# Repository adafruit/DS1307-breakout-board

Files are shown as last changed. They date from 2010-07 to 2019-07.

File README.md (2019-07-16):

## Adafruit DS1307 Real Time Clock Assembled Breakout Board PCB

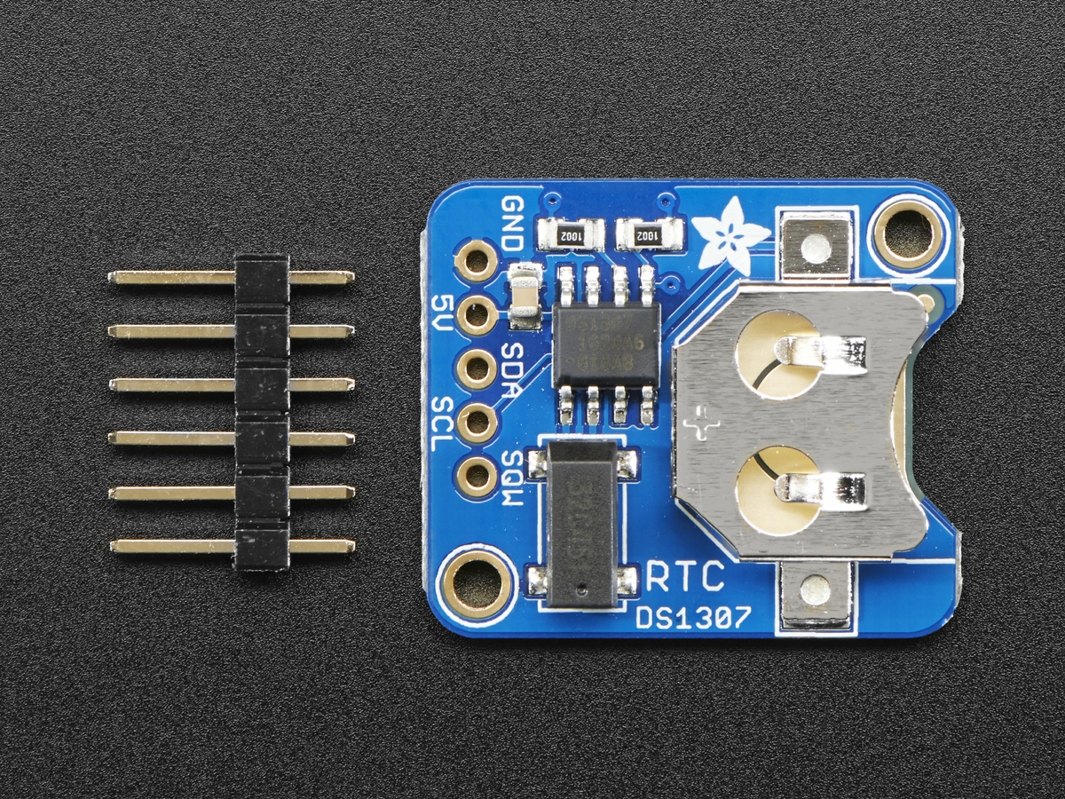
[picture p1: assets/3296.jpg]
<a href="http://www.adafruit.com/products/3296"><br/>
Click here to purchase one from the Adafruit shop</a>

PCB files for the Adafruit DS1307 Real Time Clock Assembled Breakout Board. Format is EagleCAD schematic and board layout
* https://www.adafruit.com/product/3296

### Description

This is a great battery-backed real time clock (RTC) that allows your microcontroller project to keep track of time even if it is reprogrammed, or if the power is lost. Perfect for datalogging, clock-building, time stamping, timers and alarms, etc. The DS1307 is the most popular RTC - but it requires 5V power to work (although we've used it with 5V power and 3.3V logic successfully)

Works great with an [Arduino using our RTC library](https://github.com/adafruit/RTClib) or with a [Raspberry Pi (or similar single board linux computer)](https://learn.adafruit.com/adding-a-real-time-clock-to-raspberry-pi)

The DS1307 is simple and inexpensive but not a high precision device. It may lose or gain up to 2 seconds a day. For a high-precision, temperature compensated alternative, [please check out the DS3231 precision RTC](https://www.adafruit.com/products/3013). If you do not need a DS1307, or you need a 3.3V-power/logic capable RTC please check out our affordable [PCF8523 RTC breakout](http://www.adafruit.com/products/3295)

### License

Adafruit invests time and resources providing this open source design, please support Adafruit and open-source hardware by purchasing products from [Adafruit](https://www.adafruit.com)!

Designed by Limor Fried/Ladyada for Adafruit Industries.

Creative Commons Attribution/Share-Alike, all text above must be included in any redistribution. See license.txt for additional details.

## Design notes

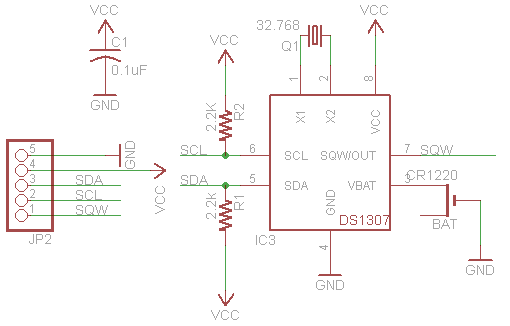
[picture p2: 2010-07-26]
ds1307.png

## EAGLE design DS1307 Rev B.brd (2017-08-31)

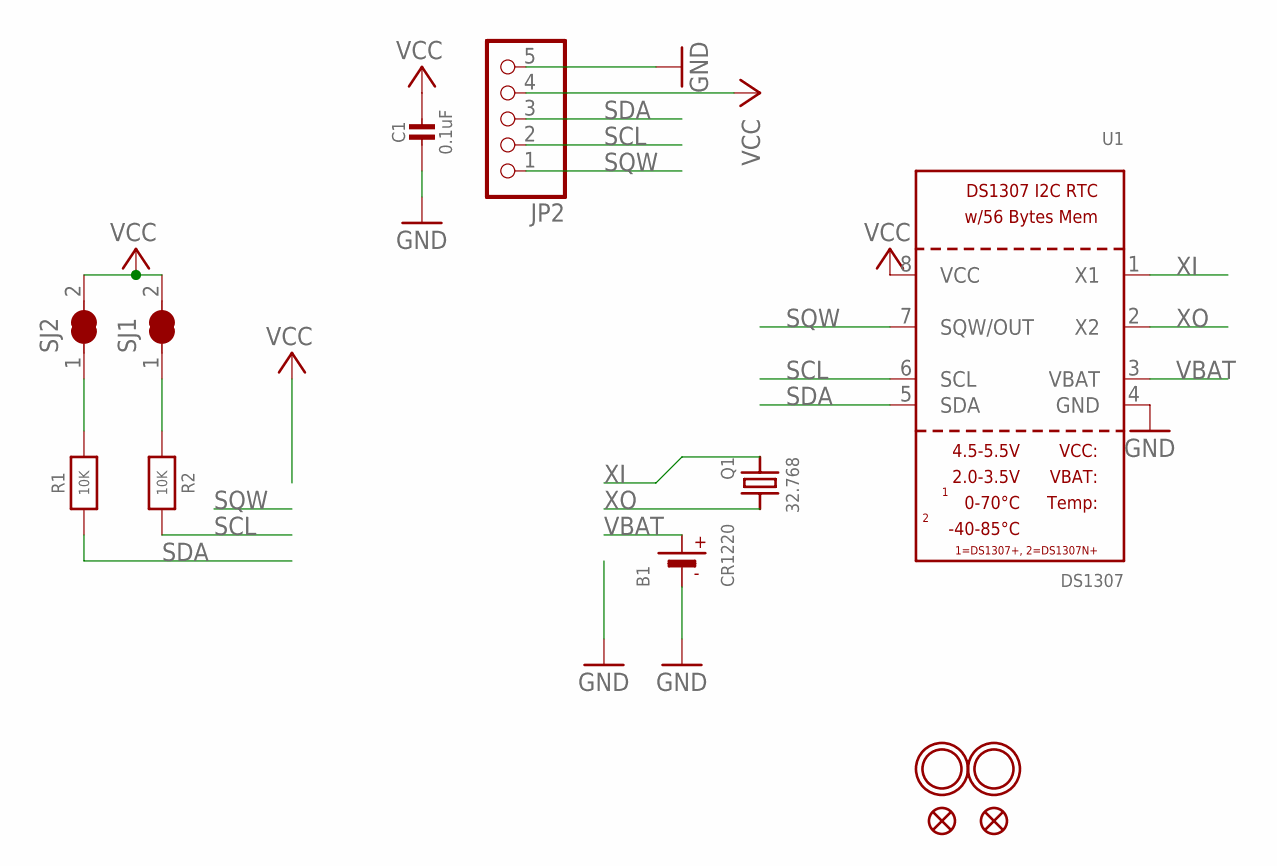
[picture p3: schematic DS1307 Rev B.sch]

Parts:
B1: CR1220
C1: 0.1uF; 0805-NO
FID1, FID2: FIDUCIAL""; FIDUCIAL_1MM
JP2: HEADER-1X576MIL; 1X05_ROUND_76
Q1: 32.768; CRYSTAL_8X3.8
R1, R2: 10K; 0805-NO
SJ1, SJ2: SOLDERJUMPER_CLOSED; SOLDERJUMPER_CLOSEDWIRE
U1: DS1307; SOIC8_150MIL
U$1, U$4: MOUNTINGHOLE2.0; MOUNTINGHOLE_2.0_PLATED

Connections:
GND: B1.-, C1.2, JP2.5, U1.4 (GND)
unnamed: R2.1, SJ1.1
unnamed: R1.2, SJ2.1
SCL: JP2.2, R2.2, U1.6 (SCL)
SDA: JP2.3, R1.1, U1.5 (SDA)
SQW: JP2.1, U1.7 (SQW/OUT)
VBAT: B1.+$1 (+), U1.3 (VBAT)
VCC: C1.1, JP2.4, SJ1.2, SJ2.2, U1.8 (VCC)
XI: Q1.P$1 (1), U1.1 (X1)
XO: Q1.P$4 (2), U1.2 (X2)

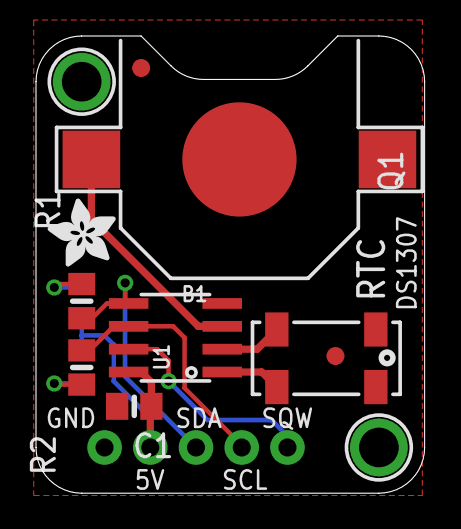
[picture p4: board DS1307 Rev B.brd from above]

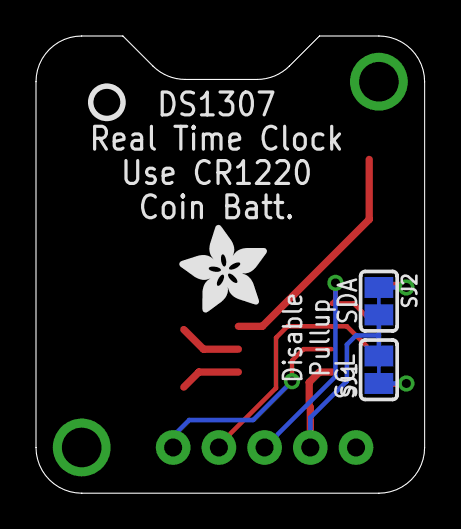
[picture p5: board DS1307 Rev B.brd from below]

Board: 2 copper layers, 21.6 x 25.4 mm, 16 parts (4 on the bottom side), 10 nets.

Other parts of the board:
U$2: ADAFRUIT_3.5MM
U$3: PCBFEAT-REV-040
U$5: ADAFRUIT_5MM

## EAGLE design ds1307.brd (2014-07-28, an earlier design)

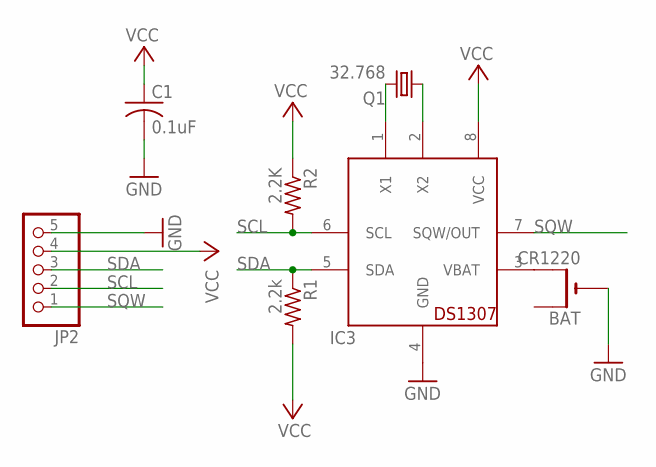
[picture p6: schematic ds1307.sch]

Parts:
BAT: CR1220; CR1220-THM
C1: 0.1uF; C025-025X050
IC3: DS1307; DIL08
JP2: PINHD-1X5; 1X05
Q1: 32.768; TC38H
R1: 2.2k; 0207/10
R2: 2.2K; 0207/10

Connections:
GND: BAT.-, C1.2, IC3.4 (GND), JP2.5
unnamed: IC3.1 (X1), Q1.2
unnamed: IC3.2 (X2), Q1.1
unnamed: BAT.+2 (+1), IC3.3 (VBAT)
SCL: IC3.6 (SCL), JP2.2, R2.2
SDA: IC3.5 (SDA), JP2.3, R1.1
SQW: IC3.7 (SQW/OUT), JP2.1
VCC: C1.1, IC3.8 (VCC), JP2.4, R1.2, R2.1

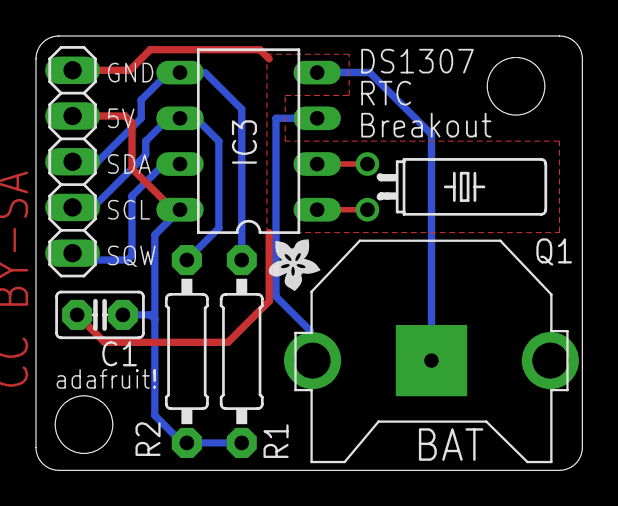
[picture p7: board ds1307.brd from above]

Board: 2 copper layers, 30.4 x 24.1 mm, 8 parts (0 on the bottom side), 8 nets.

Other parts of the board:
U$1: ADAFRUIT200MIL

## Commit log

2010-07-26 Eagle files and a photo
    [ds1307.brd, ds1307.sch]
2014-07-28 eagle 6!
    [ds1307.brd, ds1307.sch]
2017-08-31 new rev!
    [DS1307 Rev B.brd, DS1307 Rev B.sch]

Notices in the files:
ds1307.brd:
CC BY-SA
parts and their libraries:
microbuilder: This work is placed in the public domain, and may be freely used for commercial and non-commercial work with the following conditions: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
